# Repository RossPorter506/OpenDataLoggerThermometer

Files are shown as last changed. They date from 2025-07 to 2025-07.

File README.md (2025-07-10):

# OpenDatalogger Thermometer
This repository contains the hardware (schematics and PCB layout) and software for a low-cost data-logging thermometer

Powered by the Raspberry Pi Pico and it's PIO peripheral, the board is capable of supporting up to 8 digital pulse train temperature sensors, such as the LMT01. The Pico's PIO peripheral can measure all 8 sensors simultaneously. Currently the supported sampling rates are 1, 2, 4 and 8 Hz. The Pico is capable of much higher data rates if faster sensors are used.
The board contains a comparator (with optional hysteresis) for each channel to render a crisp digital signal for the PIO. The Pico can then log the values to any combination of:

1. A 20x4 character display,

2. The Pico's serial over USB, and

3. An SD card.

The board can either be powered over the Pico's built-in micro-USB connector or a dedicated USB-C connector for power.

The PCB is designed to meet JLCPCB / PCBway's special $2/$5 + shipping price. Component cost for the base station is about $50NZD, and the sensor components cost about $7NZD per channel. In total the full 8-channel configuration costs about $100NZD + shipping.

## Documentation

The PCB files are available in the 'hardware' folder. The schematic and PCB layout were designed using Altium, though these files can be opened by open-source alternatives like KiCAD.
Gerbers are not yet provided.
Schematic files are not yet provided.

Firmware is available in the 'software' folder. The firmware is written in Rust. The firmware can be compiled and flashed to a Pico with `cargo run --release`. See the README in the software folder for more details.

A desktop program to capture the (optional) serial output of the device can be found [here](https://github.com/JackDMatthews/datalogging_thermometer_gui). Development of this GUI is in the early stages, so expect bugs and missing features.

## Known issues

- The power switch does not work correctly on revision 1.0.0. SB2 should be shorted to skip over the malfunctioning Q1. 
The board will remain powered on while a USB cable is plugged in (either the USB-C power header, or the Pico's micro USB connector).

- The opamps listed in the schematic (`TLV9004IPWR`) are too slow to catch the pulses. They can be replaced with `TSV994AIPT`'s, which are pin-compatible.

### Todo list

- Update schematic with TSV994AIPT.
- Figure out issue with power switch MOSFET.
- Generate schematic and gerber files.
- Add docs for recommended configuration for optional components (hysteresis, I2C pullups, etc.)

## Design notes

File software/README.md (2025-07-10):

The software must:

Interface with LMT01 sensors via PIO
Interface with character display via I2C
Interface with SD card over SPI

Always:
Update the screen if buttons are pressed, or if new sensor data is read

On startup:
1) Allow the user to configure where values will be sent (Display, SD card, USB serial, or a combination thereof)
1b) If SD selected: Gracefully interface with an SD card (card detected?, write locked?, formatted?, free space on card? etc.)
2) Which of the 8 sensors to record/display (bonus points: Determine how many sensors are connected automatically and set missing disconnected channels to 'no')
3) Set sampling/recording rates (e.g. 1-9 samples per second per channel)

During logging:
Achieve at least 8x samples per second per sensor (using the PIO blocks)
Send values to the display, SD card and/or USB serial as necessary
Error gracefully if SD card fills up, etc.
Option to gracefully end data logging (ensure SD card can be ejected safely etc.)

Pseudocode:

```
array[8] sensor_values
array[1024] sensor_values_buffer // Buffer writes to SD card
ISR(timer) {
    ready_to_read_sensors = true
    // Optionally wake MCU up if in power save
}

button_action = none
ISR(next_button) {
    button_action = next
    // Optionally wake MCU up if in power save
}
ISR(select_button) {
    button_action = select
    // Optionally wake MCU up if in power save
}

main() {
    while configuring { // Keep this loop tight
        if button_action != none {
            update_state(button_action) // Figure out what the screen should look like
            redraw_screen(sensor_values1) // This should only take a few milliseconds(?)
            button_action = none
        }
        // Optionally sleep until buttons or timers wake MCU up
    }
    while logging { // Keep this loop tight
        if ready_to_read_sensors {
            sensor_values = read_sensors() // Reading 8 registers, no time at all
            restart_sensors() // toggle GPIO
            set_timer()
            sensor_values_buffer.append(sensor_values)
            if sensor_values_buffer.full() {
                write_to_sd = true
            }
            ready_to_read_sensors = false
            new_sensor_values = true
        }
        if new_sensor_values or button_action != none {
            update_state(button_action) // Figure out what the screen should look like, should be quick
            redraw_screen(sensor_values1)   // I2c in either normal or fast mode (check adapter). 
                                            //This should only take a few milliseconds(?)
            button_action = none
            new_sensor_values = false
        }
        if write_to_sd {
            // SD card SPI should support up to ~20MHz so this should be quick
            write_buffer_to_sd(sensor_values_buffer)
            empty_buffer(sensor_values_buffer)
            write_to_sd = false
        }
        // Optionally sleep until buttons or timers wake MCU up
    }
}
```

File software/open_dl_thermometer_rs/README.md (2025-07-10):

# Programming
Install the programmer using
`cargo install --locked elf2uf2-rs`
Change the runner in `.config/cargo.toml` to `elf2uf2-rs`
Then build and program the executable with
`cargo run` 
as usual.

# SWD/debug builds
`cargo install probe-rs-tools --locked`
Change the runner in `.config/cargo.toml` to `probe-rs`
Follow any platform-specific requirements at https://probe.rs/docs/getting-started/probe-setup

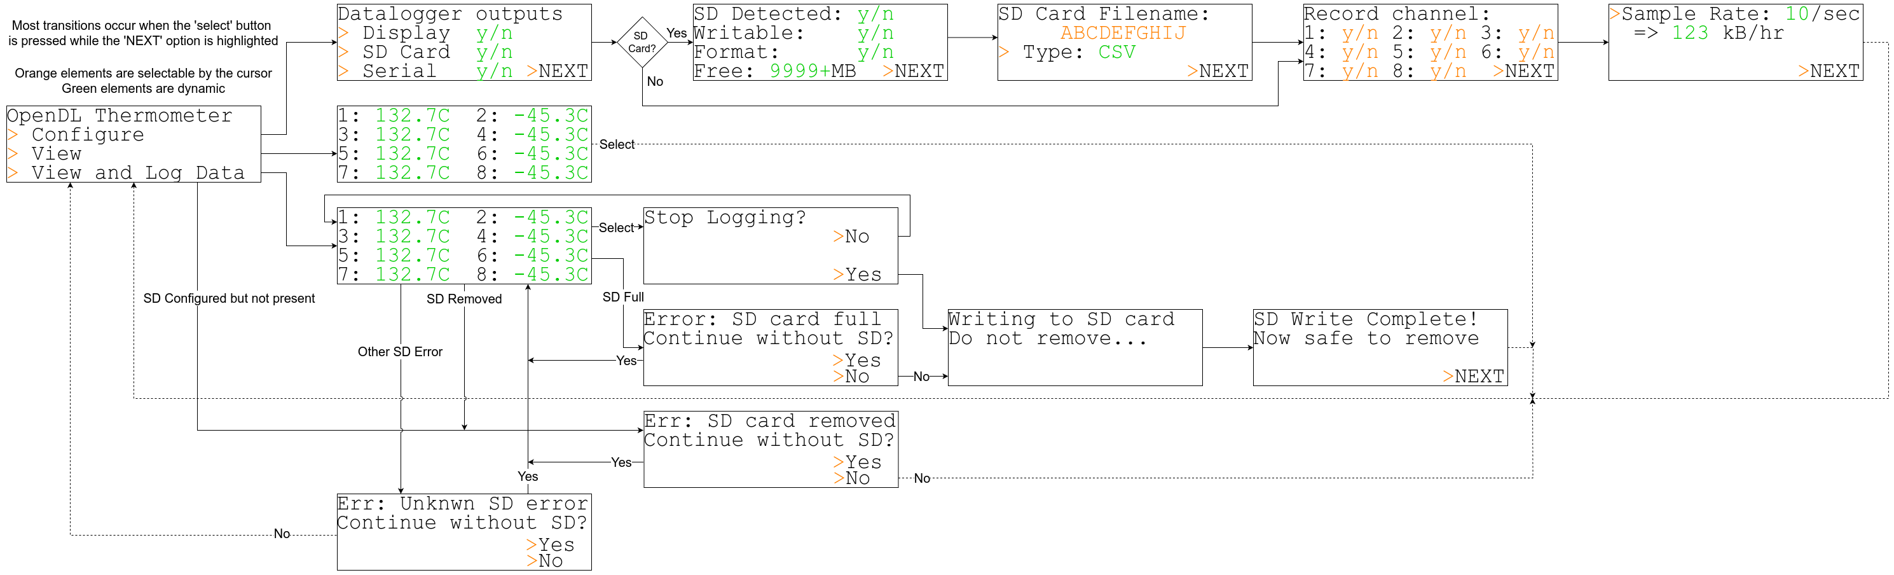
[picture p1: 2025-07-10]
software/State Machine.drawio.png

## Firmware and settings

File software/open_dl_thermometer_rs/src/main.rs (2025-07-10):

#![no_std]
#![no_main]
#![feature(variant_count)]
use core::{cell::RefCell, panic::PanicInfo, sync::atomic::{AtomicBool, AtomicU8, Ordering}};
extern crate alloc;
use alloc::string::String;

use board::Board;
use embedded_sdmmc::SdCardError;
use rp_pico::{
    entry,
    hal::{
        clocks::PeripheralClock,
        gpio, 
        pwm::{FreeRunning, Pwm0, Slice}, 
        timer::{Alarm, Alarm0}
    },
    pac::interrupt,
};
use critical_section::Mutex;
use sd_card::{SdManager, SdCardEvent};
use serial::MAX_SNAPSHOT_LEN;
use rtt_target::rprintln;
use arrayvec::ArrayString;
use atomic_enum::atomic_enum;

mod config; use config::{Config, Status::*};
mod constants; use constants::*;
mod pcb_mapping {include!("pcb_v1_mapping.rs");} 
mod lmt01;
mod display;
mod sd_card;
mod serial;
mod pio;
mod state_machine;
use state_machine::UpdateReason;
mod board;

/* TODO:
Determine sensible limits for open files/folders
Use serial printing only if configured for use, else RTT 
Test: Sensors, writing to SD card, serial
Figure out what errors should merely be printed versus those that should panic
Maybe wrap everything up into a nice struct
Stretch goal: Synchronise time with Pico W via NTP. Maybe not usable for us - cyw43 doesn't seem to support EAP WAP?
*/

#[panic_handler]
fn panic_handler(panic_info: &PanicInfo) -> ! {
    rprintln!("Panic: {:?}", panic_info);
    loop {}
}

#[entry]
fn main() -> ! {
    // High-level system configuration
    let mut config = Config::new();

    // PCB-specific configuration and interface
    let mut board = Board::configure(&mut config);
    
    let mut buffers = Buffers::new();

    rprintln!("Initialisation complete.");
    
    loop {
        // Whether we are going to update state and redraw screen
        let mut update_available: Option<UpdateReason> = None;

        // Monitor sensors
        if SENSOR_READINGS_AVAILABLE.take() {
            board.read_sensors(&mut buffers, &config);
            update_available = Some(UpdateReason::NewSensorValues);
        }
        
        if READY_TO_START_NEXT_READING.take() {
            board.start_next_sensor_reading();
        }

        // Check for button presses. This does override the `update_available` value from the above sensor readings, but
        // button presses always prompt a screen redraw anyway, so any new sensor values will be displayed regardless. 
        update_available = match BUTTON_STATE.take() {
            ButtonState::NextButton => Some(UpdateReason::NextButton),
            ButtonState::SelectButton => Some(UpdateReason::SelectButton),
            _ => update_available, // no change
        };

        // Check if the card is inserted or removed
        board.sd_manager = monitor_sdcard_state(board.sd_manager, &mut config, &mut update_available, &board.peripheral_clock);

        // Write to SD card if buffer is full
        if let Err(nb::Error::Other(e)) = board.manage_sd_writes(&mut buffers) {
            rprintln!("{:?}", e);
            update_available = Some(UpdateReason::SDError(e));
        }

        // Serial
        buffers.serial = board.manage_serial_comms(buffers.serial);

        // Service events and update available state, if required
        if let Some(update_reason) = update_available {
            config.process_events(&update_reason, board.sd_manager.get_card_info().is_ready());

            board.display_manager.determine_new_screen(&config, board.sd_manager.get_card_info(), buffers.display);
        }

        // Screen updates
        board.display_manager.incremental_update(&mut board.system_timer);
    }
}

/// Listen for an SD card being inserted or removed and initialise, if required
fn monitor_sdcard_state(mut sd_manager: SdManager, config: &mut Config, update_available: &mut Option<UpdateReason>, peripheral_clock: &PeripheralClock) -> SdManager {
    let mut sd_status: Result<(), embedded_sdmmc::Error<SdCardError>> = Ok(());

    match sd_manager.get_physical_card_events() {
        SdCardEvent::WasJustInserted => {
            *update_available = Some(UpdateReason::SDStateChange);
            sd_manager.initialise_card(peripheral_clock);
        },
        SdCardEvent::WasJustRemoved => {
            if !sd_manager.is_safe_to_remove() {
                // SD card removed unexpectedly
                // Move to SD card error screen
                *update_available = Some(UpdateReason::SDRemovedUnexpectedly);
                sd_manager = sd_manager.reset_after_unexpected_removal();
            }
            else {
                *update_available = Some(UpdateReason::SDStateChange);
            }
        },
        SdCardEvent::NoChange => (),
    }

    // Beginning to datalog
    if config.status == SamplingAndDatalogging && config.sd.selected_for_use && !sd_manager.ready_to_write() {
        let filename = alloc::format!("{}.{}", String::from_utf8_lossy(&config.sd.filename).trim(), config.sd.filetype.as_str());
        sd_status = sd_manager.try_open_file(&filename); // TODO: Ensure this function makes ready_to_write() return true.
    }
    // Just stopped datalogging
    else if config.status != SamplingAndDatalogging && config.sd.selected_for_use && !sd_manager.is_safe_to_remove() {
        // We don't need to write to the card if we're not datalogging, so make it safe to remove just in case the user removes it.
        sd_status = sd_manager.prepare_for_removal(); // TODO: Ensure this function the is_safe_to_remove() return true.
        *update_available = Some(UpdateReason::SDSafeToRemove);
    }

    if let Err(e) = sd_status {
        rprintln!("{:?}", e);
        *update_available = Some(UpdateReason::SDError(e));
        config.sd.selected_for_use = false;
    }
    sd_manager
}

/// Stores values while they wait to be sent/used.
struct Buffers {
    /// Most recent sensor values, used by the display. ASCII
    display: display::DisplayValues,
    /// We store values until we're at least as large as the block size of the SD card block size. ASCII.
    spi: ArrayString::<{MAX_SNAPSHOT_LEN*11}>, // 11 is arbitrary. Gets us to 91*11 = 1001 bytes, with a 512 block size it's pretty close to 2 blocks
    /// We will write to serial as we receive, so buffer need only be big enough for one lot of readings. ASCII.
    serial: ArrayString::<MAX_SNAPSHOT_LEN>,
}
impl Buffers {
    pub fn new() -> Self {
        let display = [None; NUM_SENSOR_CHANNELS];
        let spi = ArrayString::new();
        let serial = ArrayString::new();
        Self {display, spi, serial}
    }
}

/// Whether it's time to read the sensors for new values
static SENSOR_READINGS_AVAILABLE: AtomicBool = AtomicBool::new(false);

/// Timer used to tell when sensor readings are ready to be read.
static SENSORS_READY_TIMER: Mutex<RefCell< Option<Alarm0> >> = Mutex::new(RefCell::new(None)); 

// Set flag indicating we should check sensor values
// Interrupt fires 105ms after sensors are reset, values should be ready now.
#[interrupt]
fn TIMER_IRQ_0() {
    SENSOR_READINGS_AVAILABLE.set(true);
    critical_section::with(|cs| {
        let Some(ref mut timer) = *SENSORS_READY_TIMER.borrow_ref_mut(cs) else {unreachable!()};
        timer.clear_interrupt();
    });
}

/// The default sample frequency of the system on startup, in Hz.
const DEFAULT_SAMPLE_FREQ_HZ: u8 = 1;

/// Timer used to count out multiples of 125ms periods, used to determine when new readings should be taken.
static SAMPLE_RATE_TIMER: Mutex<RefCell< Option<Slice<Pwm0, FreeRunning>> >> = Mutex::new(RefCell::new(None)); 

/// How many times the 8Hz PWM interrupt must trigger per sample of the sensors, e.g.
/// 
/// `WRAPS_PER_SAMPLE = 8/n` where `n` is the sampling frequency
static WRAPS_PER_SAMPLE: AtomicU8 = AtomicU8::new(8/DEFAULT_SAMPLE_FREQ_HZ);

/// Whether it's time to reset the sensors to generate new values
static READY_TO_START_NEXT_READING: AtomicBool = AtomicBool::new(false);
// Interrupt fires some multiple of 125ms (based on sample rate). Used to schedule sensor resets
#[interrupt]
fn PWM_IRQ_WRAP() {
    static NUM_WRAPS: AtomicU8 = AtomicU8::new(1);
    
    if NUM_WRAPS.get() >= WRAPS_PER_SAMPLE.get() {
        READY_TO_START_NEXT_READING.set(true);
        NUM_WRAPS.set(1);
    }
    else { NUM_WRAPS.set(NUM_WRAPS.get()+1); }

    critical_section::with(|cs| {
        let Some(ref mut timer) = *SAMPLE_RATE_TIMER.borrow_ref_mut(cs) else { unreachable!() };
        timer.clear_interrupt();
    });
}

/// Whether any buttons have been pressed
static BUTTON_STATE: AtomicButtonState = AtomicButtonState::new(ButtonState::None);
/// Interrupt-accessible container for button pins. 'None' until interrupt is configured by `configure_button_pins`.
static BUTTON_PINS: Mutex<RefCell<Option<pcb_mapping::ButtonPins>>> = Mutex::new(RefCell::new(None));
// Next and Select button interrupts. Set flags for main process. 
// We don't really care if both buttons are pressed at once. Hopefully the main loop should be tight enough not to matter
#[interrupt]
fn IO_IRQ_BANK0() {
    critical_section::with(|cs| {
        let Some(ref mut buttons) = *BUTTON_PINS.borrow_ref_mut(cs) else { unreachable!() };
            if buttons.select.interrupt_status(gpio::Interrupt::EdgeLow) {
                BUTTON_STATE.set(ButtonState::SelectButton);
                buttons.select.clear_interrupt(gpio::Interrupt::EdgeLow);
            } else if buttons.next.interrupt_status(gpio::Interrupt::EdgeLow) {
                BUTTON_STATE.set(ButtonState::NextButton);
                buttons.next.clear_interrupt(gpio::Interrupt::EdgeLow);
        }
    });
}

/// Whether buttons have been pressed
#[atomic_enum]
#[derive(PartialEq, Default)]
enum ButtonState {
    #[default]
    None = 0,
    NextButton,
    SelectButton,
}

/// Convenience trait for relaxed atomic reads/writes.
trait RelaxedIO {
    type Inner;
    /// Gets the inner value, relaxed ordering
    fn get(&self) -> Self::Inner;
    /// Gets the inner value and replaces it with the default, relaxed ordering.
    fn take(&self) -> Self::Inner;
    /// Sets the inner value, relaxed ordering
    fn set(&self, val: Self::Inner);
}
macro_rules! impl_relaxedio_for {
    ($type: ty, $inner: ty) => {
        impl RelaxedIO for $type {
            type Inner = $inner;
            fn get(&self) -> Self::Inner { self.load(Ordering::Relaxed) }
            fn set(&self, val: Self::Inner) { self.store(val, Ordering::Relaxed); }
            fn take(&self) -> Self::Inner{ 
                let val = self.load(Ordering::Relaxed); 
                self.store(Default::default(), Ordering::Relaxed);
                val
            }
        }
    };
}
impl_relaxedio_for!(AtomicU8, u8);
impl_relaxedio_for!(AtomicBool, bool);
impl_relaxedio_for!(AtomicButtonState, ButtonState);

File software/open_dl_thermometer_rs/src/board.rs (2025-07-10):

// Does top-level configuration of board-specific parameters

use crate::{
    config::{Config, Status}, 
    display::IncrementalDisplayWriter, eprintln, lmt01::{self, TempSensors}, 
    pcb_mapping::{self, ButtonPins, DisplayPins, DisplayScl, DisplaySda, SdCardExtraPins, SdCardMiso, SdCardMosi, SdCardPins, SdCardSPIPins, SdCardSck, TempPowerPins, TempSensePins}, 
    println, 
    sd_card::{self, SdCardInfo, SdManager}, 
    serial::{self, nonblocking_read, MAX_SNAPSHOT_LEN}, Buffers, RelaxedIO};

use arrayvec::ArrayString;
use embedded_sdmmc::SdCardError;
use liquid_crystal::DelayNs;
use rp_pico::{
    hal::{clocks::{ClocksManager, PeripheralClock, RtcClock, SystemClock, UsbClock}, 
    fugit::{ExtU32, RateExtU32}, gpio, pwm::FreeRunning, 
    rtc::{DateTime, DayOfWeek, RealTimeClock}, spi, timer::Alarm, usb::UsbBus, Clock, Sio, Spi, Timer, Watchdog, I2C}, 
    pac::{self, CLOCKS, I2C0, IO_BANK0, PADS_BANK0, PIO0, PIO1, PLL_SYS, PLL_USB, PWM, RESETS, RTC, SIO, SPI0, TIMER, USBCTRL_DPRAM, USBCTRL_REGS, WATCHDOG, XOSC},};
use rtt_target::rtt_init_print;

pub struct Board {
    pub system_timer: Timer,
    pub usb_device: UsbDevice<'static, UsbBus>,
    pub sd_manager: SdManager,
    write_to_sd: bool,
    pub display_manager: IncrementalDisplayWriter<'static>,
    pub temp_sensors: TempSensors,
    pub peripheral_clock: PeripheralClock,
}
impl Board {
    pub fn configure(config: &mut Config) -> Self {
        rtt_init_print!();
        configure_heap();
        // Take ownership of peripherals
        let Some(mut registers) = pac::Peripherals::take() else { unreachable!() };
        
        // GPIO pin groups
        let (temp_power, temp_sense, sdcard_pins, display_pins) = collect_pins(registers.SIO, registers.IO_BANK0, registers.PADS_BANK0, &mut registers.RESETS);

        // System clocks
        let (_watchdog, clocks) = configure_clocks(registers.WATCHDOG, registers.XOSC, registers.CLOCKS, registers.PLL_SYS, registers.PLL_USB, &mut registers.RESETS);

        // Timers
        let mut system_timer = configure_timers(registers.PWM, registers.TIMER, &mut registers.RESETS, &clocks);

        // USB - Also enables USB serial printing
        let usb_device = configure_usb(registers.USBCTRL_REGS, registers.USBCTRL_DPRAM, &mut registers.RESETS, clocks.usb_clock);

        // SD card manager
        let mut sd_manager = configure_sdcard(registers.SPI0, registers.RTC, sdcard_pins, clocks.rtc_clock, system_timer, &mut registers.RESETS, &clocks.peripheral_clock);
        // Write controls for SD card. false when transmissions are complete, for now
        let write_to_sd = false;

        // Display
        let display_manager = configure_display(registers.I2C0, display_pins, sd_manager.get_card_info(), config, &clocks.system_clock, &mut system_timer, &mut registers.RESETS);

        // Temp sensors
        let mut temp_sensors = configure_sensors(registers.PIO0, registers.PIO1, temp_sense, temp_power, &mut registers.RESETS);

        // Autodetect any connected sensors
        config.enabled_channels = temp_sensors.autodetect_sensor_channels(&mut system_timer);

        Board {system_timer, usb_device, sd_manager, write_to_sd, display_manager, temp_sensors, peripheral_clock: clocks.peripheral_clock}
    }

    /// Read values from the LMT01 sensors and update buffers
    pub fn read_sensors(&mut self, buffers: &mut Buffers, config: &Config) {

        buffers.display = self.temp_sensors.read_temperatures_and_end_conversion().map(lmt01::temp_to_string);

        // TODO: Technically this timestamp value should probably be from when the conversion *started*, not when it ended, but only 0.1sec difference
        let serialised_snapshot = serial::serialise_snapshot(self.system_timer.get_counter(), &buffers.display);

        if config.status == Status::SamplingAndDatalogging {
            if config.sd.selected_for_use {
                if buffers.spi.try_push_str(&serialised_snapshot).is_err() {
                    eprintln!("SPI buffer overfull! Dropping data: {}", serialised_snapshot.as_str());
                    self.write_to_sd = true;
                }
                if buffers.spi.is_full() { self.write_to_sd = true; }
            }
    
            if config.serial.selected_for_use {
                buffers.serial = serialised_snapshot;
            }
        }

        crate::SENSOR_READINGS_AVAILABLE.set(false);
    }

    /// If it's time to get another reading then restart the LMT01 sensors.
    pub fn start_next_sensor_reading(&mut self) {
        self.temp_sensors.begin_conversion();
        critical_section::with(|cs| {
            let Some(ref mut timer) = *crate::SENSORS_READY_TIMER.borrow_ref_mut(cs) else { unreachable!() };
            timer.schedule((lmt01::SENSOR_MAX_TIME_FOR_READING_MS).millis()).unwrap_or_else(|_| unreachable!());
        });
        crate::READY_TO_START_NEXT_READING.set(false);
    }


    /// Try to send data over serial.
    pub fn manage_serial_comms(&mut self, serial_buffer: ArrayString::<MAX_SNAPSHOT_LEN>) -> ArrayString::<MAX_SNAPSHOT_LEN>{
        // Has something been sent or received since last time?
        let new_events = critical_section::with(|cs| -> bool {
            let Some(ref mut serial) = *serial::USB_SERIAL.borrow_ref_mut(cs) else { unreachable!() };
            self.usb_device.poll(&mut [serial])
        });

        if new_events {
            // Read the serial buffer, check for ping requests
            Self::check_for_and_respond_to_pings();

            // Try to send everything we need to send
            if !serial_buffer.is_empty() {
                use serial::UsbSerialPrintError::*;
                return match serial::nonblocking_print(serial_buffer.as_bytes()) {
                    // Remove whatever was successfully sent from our buffer
                    Err(WouldBlock(len)) => ArrayString::from(&serial_buffer[len..]).unwrap_or_else(|_| unreachable!() ),
                    Err(OtherError(a)) => panic!("{a:?}"),
                    Ok(()) => ArrayString::new(),
                };
            }
        }
        
        serial_buffer
    }

    /// Reads the serial recieve buffer. If we receive an ASCII ENQ character respond with an ASCII ACK.
    fn check_for_and_respond_to_pings() {
        let mut buf = [0u8; 8];
        const ASCII_ENQ_CHAR: u8 = b'\x05';
        const ASCII_ACK_STR: &str = "\x06";
        use serial::UsbSerialReadError::*;
        match nonblocking_read(buf.as_mut_slice()) {
            Err(WouldBlock) => (), // Recieve buffer empty
            Ok(len) => {
                let enq_count = buf.iter().take(len).filter(|&&c| c == ASCII_ENQ_CHAR).count();
                let response = str::repeat(ASCII_ACK_STR, enq_count);
                println!("{response}"); // This is technically a blocking write, but...
            },
            Err(OtherError(e)) => panic!("{e:?}"),
        }
    }
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

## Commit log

2024-10-07 Start schematic
    Add initial Rpi pico pin layout
    TODO: Display symbol + footprint, SD card reader, LMT01 interface
    [DataLoggingThermometer.PrjPcb, Mainboard.PcbDoc, Mainboard.SchDoc]
2024-10-07 Add buttons, LMT01 interface
    Using picoblade 2-pin headers
    [DataLoggingThermometer.PrjPcb, Mainboard.SchDoc]
2024-10-08 Add display, SD card. Initial Layout
    [DataLoggingThermometer.PrjPcb, Mainboard.PcbDoc, Mainboard.SchDoc]
2024-10-08 Initial Routing
    Lined up holes to allow mounting display over PCB maybe?
    [DataLoggingThermometer.PrjPcb, Mainboard.PcbDoc, Mainboard.SchDoc]
2024-10-08 Move buttons to allow display mounted above PCB
    Also define outline of software requirements
    [Mainboard.PcbDoc]
2024-10-09 Add missing component parameters
    Fix C0805C226M9PACTU incorrect footprint parameter.
    Add relevant parameters for missing parts
    [Mainboard.SchDoc]
2024-10-09 Add mechanical parts to represent off-board sensors + BoM tidying
    [DataLoggingThermometer.PrjPcb, Mainboard.PcbDoc, Mainboard.SchDoc]
2024-10-09 Fix display voltage
    Should be powered off 5V not 3V3
    [Mainboard.SchDoc]
2024-10-10 Add power switch + LED
    Requires a MOSFET. Bridge SB2 to skip it.
    [DataLoggingThermometer.PrjPcb, Mainboard.PcbDoc, Mainboard.SchDoc]
2024-10-11 Add comparators to LMT01 sensor outputs
    Almost forgot to put these on
    Schmitt trigger optional
    [DataLoggingThermometer.PrjPcb, LMT01 Interface.schdoc, Mainboard.SchDoc]
2024-10-12 Add Readme, tidy BoM
    Make sure all components have a part number.
    Minimise unique part count by reusing resistor values, etc.
    [DataLoggingThermometer.PrjPcb, LMT01 Interface.schdoc, Mainboard.SchDoc]
2024-10-12 PIO program attempt 1
    Don't have a pico to test with yet. Might use an emulator for now
2024-10-13 Add test points, button debouncing, silk layout
    [DataLoggingThermometer.PrjPcb, Mainboard.SchDoc]
2024-10-13 Test and update PIO program
    Simulated PIO program with https://github.com/soundpaint/rp2040pio
    Unfortunately MOV doesn't trigger autopush, so the CPU will have to invert the result itself.
    The OUT NULL 32 and MOV Y ! NULL commands can be executed in the C program to save a couple of instructions. Not that anything else is going to use the PIO instruction memory anyway...
2024-10-20 Tidy up PCB, make on/off switch default
    [Mainboard.SchDoc]
2024-10-26 Fill out medium-level logic
    Use DynPin type to erase types for TempPower pins.
    Remove UART configuration state since we're actually using USB serial, whoops. Refactor names to match.
    Start LMT01 driver. Haven't set up PIO or anything yet.
    Start work on display logic.
    Fix wrong GPIO function on SD card detect and write protect pins.
    [display.rs, main.rs, pcb_v1_mapping.rs]
2024-10-29 Slightly correct distance of mounting holes
2024-10-29 Add heap to simplify display code. Add todo list
    We probably ought to use the heap for the SPI buffer anyway, it's kinda big for the stack.
2024-10-30 Add timers
    Restrict sample rate to 1, 2, 4, 8 Hz to keep things simple. Use a periodic 125ms timer (PWM peripheral) to set a flag to reset sensors. After they are reset a one-off 105ms timer is started to get the sensor readings when they're ready.
    [main.rs, pcb_v1_mapping.rs]
2024-10-31 Configure SPI and I2C buses for use
    Also fix I2C pin definition typo
    Refactor ButtonState names
    [main.rs, pcb_v1_mapping.rs]
2024-11-01 Refactor PIO module
    Store state machines as an array of Box<dyn AnyPioStateMachine> so we can iterate over them instead of doing each one manually. Yes they're on the heap now, but we only read a single byte from each state machine every ~100ms.
    Move LMT01-specific configuration to lmt01.rs
    Bug fix: Invert count after retrieval from PIOs
    [main.rs]
2024-11-01 Start display driver
    Use liquid_crystal library - support for async (maybe in the future). custom characters, etc.
    Drawing the whole screen may be too slow, so do an incremental screen draw where we write one character to the screen at a time.
    [display.rs]
2024-11-02 Display: Instantiate driver in new fn, add docstrings
    Refactor SCREEN_WIDTH to SCREEN_COLS
2024-11-02 Display: Set up cursor support, integrate into main
    Bugfix: Actually deal with the next button somewhere.
    Reshuffle main loop so we don't potentially throw out button presses for sensor values. The sensor values are recorded anyway.
    [display.rs, main.rs]
2024-11-03 Autodetect connected sensors
2024-11-03 Add I2C external pullup footprints
    Just in case the internal pullups aren't good enough.
    [DataLoggingThermometer.PrjPcb, Mainboard.SchDoc]
2024-11-03 Prepare for manufacture
    [DataLoggingThermometer.PrjPcb]
2024-11-08 Actually update the sample rate properly
2024-11-09 added is inserted method in sd manager
2024-11-10 this is the error with the pins
    [main.rs, sd_card.rs]
2024-11-13 Bugfix: LMT01 power pins not changing type
    [pcb_v1_mapping.rs]
2024-11-14 Edits to sd_card
    Remove calls to .unwrap() in open_file() as these may actually fail. Use let-else pattern matching to continue instead.
    Change is_card_formatted to a non-static method
    Add more stubbed functions.
    Unrelated: Check to see if SD card is ok before continuing to SD filename screen.
    [main.rs, sd_card.rs]
2024-11-15 Begin debug print implementation
    Move USB serial bus to static var to enable printing anywhere. Write helper functions
2024-11-16 Add SD insertion check before datalogging
    Also some config depends only on current state, so refactor them out to their own function under state_machine::state_outputs()
2024-11-16 Implement serialisation, refactor display code
    Instead of taking Option<[[u8; CHARS_PER_READING]; NUM_CHANNELS]> instead take [Option<[u8; CHARS_PER_READING]>; NUM_CHANNELS]. This works a lot better with some channels potentially not being activa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
    Move the three buffers (spi, display, serial) into a struct to carry around easier.
2024-11-17 Move USB initialisation further up main to print earlier
2024-11-18 Add print functions, refactor ArrayVec<u8> to ArrayString to print
    Also add helper function to SDConfig to reset after card removal
    Append file extension to filename for SD writing
    [display.rs, main.rs, sd_card.rs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]
2024-11-20 fixed error printing in sd card manager
    [sd_card.rs]
2024-11-21 Improve printing ergonomics
    Make sure errors occur at macro invocation, not at nested macro definitions by using format_args!.
    Also switch to using full fat printing for now. ufmt is a pain to work with.
    Make sure core::fmt::Write is in scope when write! is called.
    [serial.rs]
2024-11-21 Add README for programming
    Plus fix typo in display
    [display.rs]
2024-11-21 Printing fixes
    Don't `take()` Mutex<RefCell>, instead `borrow_ref_mut()`
    Ensure mutable references to USB_SERIAL don't overlap
    Remove unused import in sd_card
    [main.rs, sd_card.rs, serial.rs]
2024-11-27 RTT debug printing
2024-11-27 Overhaul SD card error handling
    Add generic SD card error state, and UpdateReason variant. Bubble SD card errors up to main.
    [display.rs, main.rs, sd_card.rs]
2024-11-29 Screen debugging
    Need to call .begin() during initialisation, also need to call set_cursor every time we move to a new line, as the lines aren't contiguous in memory and they appear in the wrong order on the display.
    [display.rs, main.rs]
2024-11-29 Tidy main, move details to subfunctions
    SD card now keeps track of insertion state
    Sensors, display, SD card now have configuration functions
2024-12-03 Close root dir correctly
    [sd_card.rs]
2024-12-17 Fix sample rate initial value
    Fix sample rate starting at 0.
2024-12-17 Clear conditions after checks
    Also clear button interrupt flags before interrupts are enabled during button configuration
2024-12-17 Add constants for SPI, I2C speeds
2024-12-17 Misc bugfixes
    Remove outdated docstring.
    Only initialise SD card if it's selected for use.
    Derive Debug on states so I can print out the state during debugging.
    Avoid serial printing prior to serial being selected for use, could block.
    [main.rs]
2024-12-19 Fix typecast in SD card free space display calculation
    Incorrectly typecasting u64 to usize before division
    [display.rs]
2024-12-19 Fix state transitions
    Mainmenu -> Datalog check already handled in the manage_sd function
    Add the SDSafeToRemove update after making SD card safe to remove. Oops.
    [main.rs]
2024-12-19 Synchronise default sample rate with WRAPS_PER_SAMPLE
2024-12-19 Update screen when SD card added or removed
    Used in the SD status screen, don't want the user to have to hit a button to see the new status
2024-12-19 Fix cursor position for dynamic selectable elements
    Cursor position needs to be set after the screen has finished being drawn, not beforehand.
    Flashing cursor was a bit overwhelming, so just use the underscore cursor.
    [display.rs, main.rs]
2024-12-19 Configure timer interrupts
    Enable NVIC registers to actually enable interrupts.
    Clear interrupts inside ISRs to prevent continuous interrupts.
    Also fix off-by-one error on PWM timer period.
    [main.rs]
2024-12-19 Fix RTT print statements
    Can't do internal substitution, unlike with println
    Also update todo list
    [main.rs]
2024-12-19 Remove placeholder USB device strings
    Also fix capitalisation in main readme
    [main.rs]
2024-12-22 Allow printing of custom characters
    Strings whose first byte is 0x0 to 0x7 will instead print the equivalent custom character.
2025-03-24 Refactor screen printing
    Was getting a bit messy. This should act the same but deals with all the edge cases nicer.
2025-03-26 Refactor into board struct
    Refactor all the PCB-specific things into Board. Make Config the high-level config for the rest of the project (i.e. Config deals with things not related to the PCB but that is related to the project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
2025-05-08 Start probe-rs setup for debugging
    Need to debug pulse counter
2025-07-09 PIO configuration + LUT bounds + NUM_WRAPS race condition bugfix
    [main.rs]
2025-07-10 Prevent empty SD filename + only check SD if datalogging
    [board.rs]
2025-11-21 Remove unnecessary unwrap_infallible()'s
    New compiler version doesn't warn on unused Result<(), Infallible>
    [pcb_v1_mapping.rs, sd_card.rs]
